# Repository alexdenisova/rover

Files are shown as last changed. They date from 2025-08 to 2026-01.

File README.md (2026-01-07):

# Rover

An STM32 + ESP32 remote controller for a Yandex Rover toy that executes voice commands: "Forward", "Backward", "Right", "Left", "Spin", "Open", "Close".

As OpenAI's Whisper is rather slow at transcribing the audio, it takes several seconds for the rover to react to the oral command. In the future, I plan to train my own speech-to-text model in the hopes of making it quicker.

## How it works

The user says one of the commands, which is recorded by the MAX9814 microphone either onto the SD card or to the ESP32. The ESP32 creates a WAV file from the audio and sends it to the "Speech-to-Text" server that uses OpenAI's Whisper to transcribe the audio. Then, based on the command received, the STM32 sends an IR signal to the rover, who then completes the command.

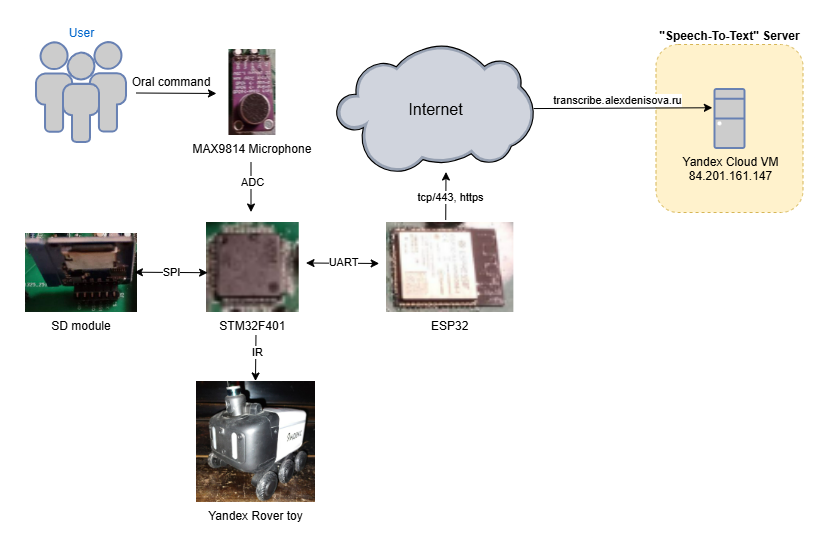
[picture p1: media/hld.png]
HLD

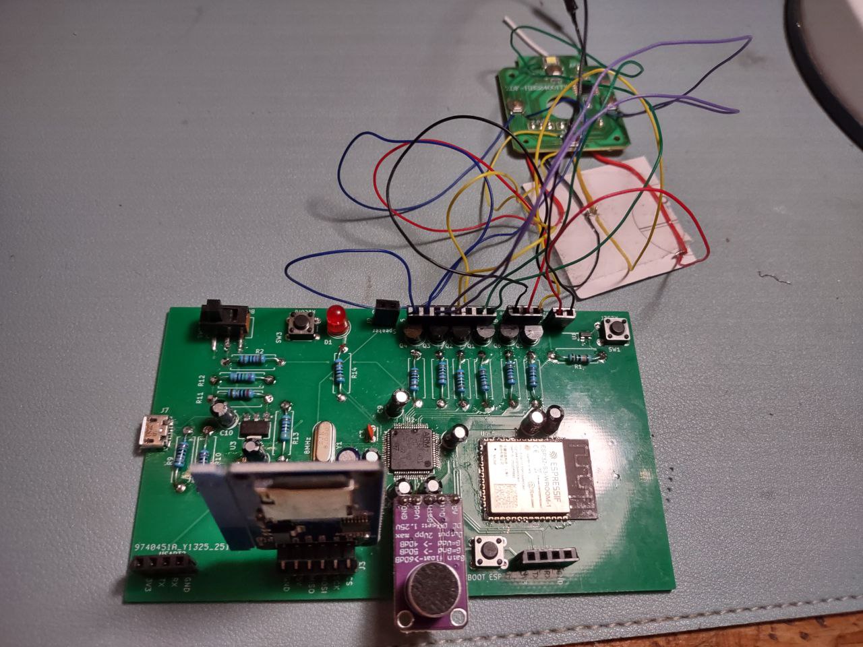
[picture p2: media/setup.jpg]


## Video

In the demonstration, I give the command "Forward". The rover takes several seconds to react, as the speech-to-text model is rather slow at transcribing.

https://github.com/user-attachments/assets/662a4837-75a4-4f81-b607-461e728f610d

## Photos

<p float="left">
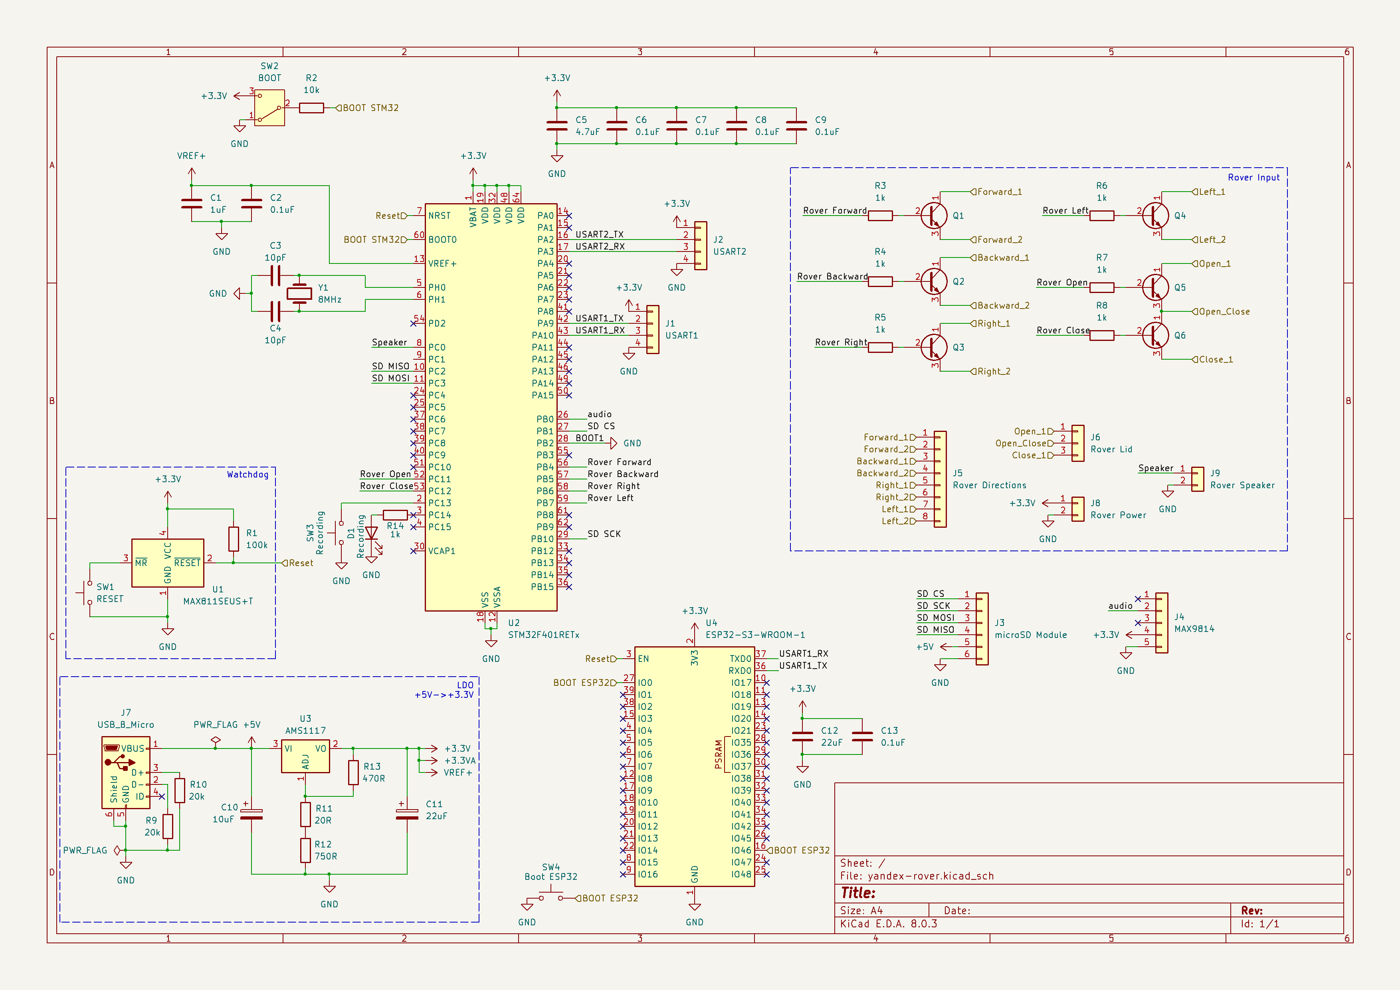
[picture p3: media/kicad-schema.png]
    
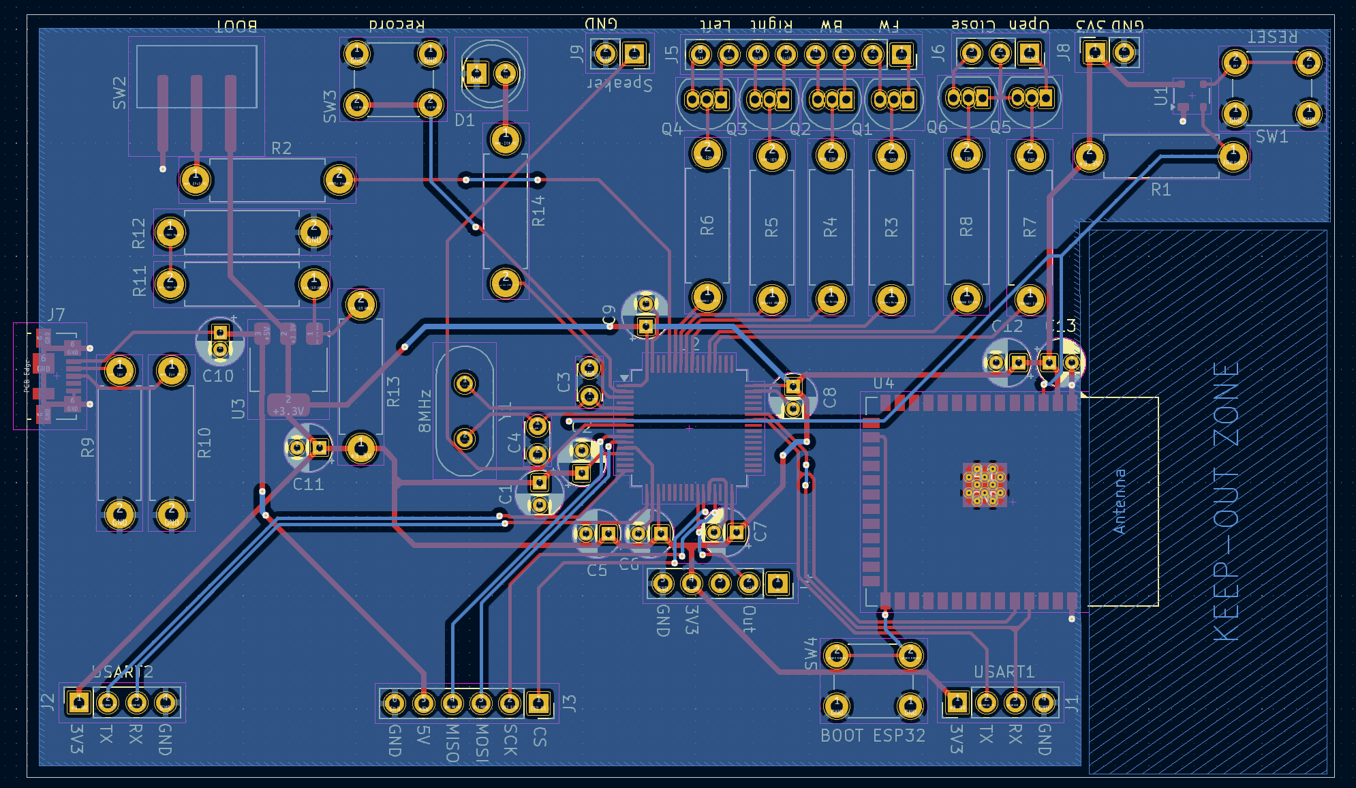
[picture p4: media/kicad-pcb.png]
    
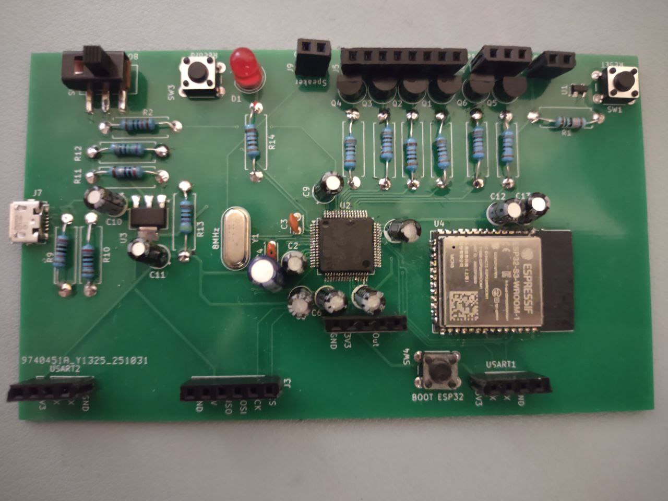
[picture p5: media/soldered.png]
    
</p>

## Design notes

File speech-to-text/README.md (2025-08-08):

# Speech-to-Text Server

A Speech-to-Text API based on OpenAI Whisper used to transcribe audio for Rover instructions. Currently, only one file at a time can be processed.

To transcribe audio use:
`curl -X POST -F "file=@/path/audio.wav" http://transcribe.alexdenisova.net/transcribe`

or with chunks:
`curl -X POST -H "Content-Range: bytes 0-1048999/2322510" -F "file=@/path/to/chunk" http://transcribe.alexdenisova.net/transcribe`

The server is deployed in a local cluster, which is located in the same network as the Rover.

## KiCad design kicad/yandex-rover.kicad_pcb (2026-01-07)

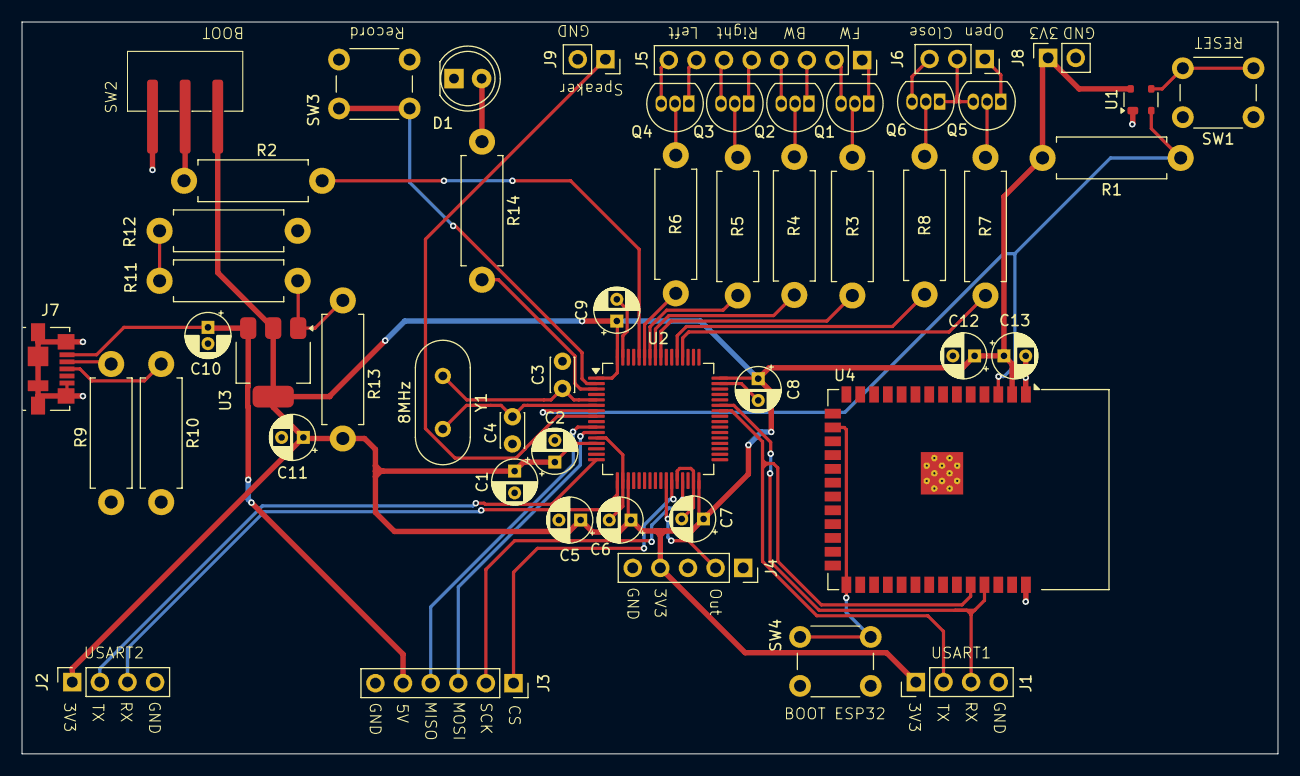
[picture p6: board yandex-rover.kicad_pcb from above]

Board: 2 copper layers, 115.5 x 67.3 mm, 52 parts (0 on the bottom side), 49 nets.

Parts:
C1: 1uF; CP_Radial_D4.0mm_P2.00mm
C2, C6, C7, C8, C9, C13: 0.1uF; CP_Radial_D4.0mm_P2.00mm
C3, C4: 10pF; C_Disc_D3.0mm_W2.0mm_P2.50mm
C5: 4.7uF; CP_Radial_D4.0mm_P2.00mm
C10: 10uF; CP_Radial_D4.0mm_P1.50mm
C11, C12: 22uF; CP_Radial_D4.0mm_P2.00mm
D1: Recording; LED_D5.0mm
J1: USART1; PinHeader_1x04_P2.54mm_Vertical
J2: USART2; PinSocket_1x04_P2.54mm_Vertical
J3: microSD Module; PinSocket_1x06_P2.54mm_Vertical
J4: MAX9814; PinSocket_1x05_P2.54mm_Vertical
J5: Rover Directions; PinSocket_1x08_P2.54mm_Vertical
J6: Rover Lid; PinSocket_1x03_P2.54mm_Vertical
J7: USB_B_Micro; USB_Micro-B_Molex_47346-0001
J8: Rover Power; PinSocket_1x02_P2.54mm_Vertical
J9: Rover Speaker; PinSocket_1x02_P2.54mm_Vertical
Q1, Q2, Q3, Q4, Q5, Q6: TO-92_Inline
R1: 100k; R_Axial_DIN0411_L9.9mm_D3.6mm_P12.70mm_Horizontal
R2: 10k; R_Axial_DIN0411_L9.9mm_D3.6mm_P12.70mm_Horizontal
R3, R4, R5, R6, R7, R8, R14: 1k; R_Axial_DIN0411_L9.9mm_D3.6mm_P12.70mm_Horizontal
R9, R10: 20k; R_Axial_DIN0411_L9.9mm_D3.6mm_P12.70mm_Horizontal
R11: 20R; R_Axial_DIN0411_L9.9mm_D3.6mm_P12.70mm_Horizontal
R12: 750R; R_Axial_DIN0411_L9.9mm_D3.6mm_P12.70mm_Horizontal
R13: 470R; R_Axial_DIN0411_L9.9mm_D3.6mm_P12.70mm_Horizontal
SW1: RESET; SW_PUSH_6mm_H4.3mm
SW2: BOOT; KLS7-SS-12F19-G5
SW3: Recording; SW_PUSH_6mm
SW4: Boot ESP32; SW_PUSH_6mm
U1: MAX811SEUS+T; SOT-143
U2: STM32F401RETx; LQFP-64_10x10mm_P0.5mm
U3: AMS1117; SOT-223-3_TabPin2
U4: ESP32-S3-WROOM-1
Y1: 8MHz; Crystal_HC49-4H_Vertical

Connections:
+3.3V: C1.1, C2.1, C5.1, C6.1, C7.1, C8.1, C9.1, C11.1, C12.1, C13.1, J1.1, J2.1, J4.4, J8.1, R1.2, R13.1, SW2.3 (C), U1.4 (VCC), U2.1 (VBAT), U2.13 (VREF+), U2.19 (VDD), U2.32 (VDD), U2.48 (VDD), U2.64 (VDD), U3.2 (VO), U4.2 (3V3)
+5V: C10.1, J3.5, J7.1 (VBUS), U3.3 (VI)
/BOOT ESP32: SW4.2, U4.16 (IO46), U4.27 (IO0)
/BOOT STM32: R2.2, U2.60 (BOOT0)
/Backward_1: J5.3, Q2.1 (C)
/Backward_2: J5.4, Q2.3 (E)
/Close_1: J6.3, Q6.3 (E)
/Forward_1: J5.1, Q1.1 (C)
/Forward_2: J5.2, Q1.3 (E)
/Left_1: J5.7, Q4.1 (C)
/Left_2: J5.8, Q4.3 (E)
/Open_1: J6.1, Q5.1 (C)
/Open_Close: J6.2, Q5.3 (E), Q6.1 (C)
/Reset: R1.1, U1.2 (~RESET), U2.7 (NRST), U4.3 (EN)
/Right_1: J5.5, Q3.1 (C)
/Right_2: J5.6, Q3.3 (E)
/Rover Backward: R4.1, U2.57 (PB5)
/Rover Close: R8.1, U2.53 (PC12)
/Rover Forward: R3.1, U2.56 (PB4)
/Rover Left: R6.1, U2.59 (PB7)
/Rover Open: R7.1, U2.52 (PC11)
/Rover Right: R5.1, U2.58 (PB6)
/SD CS: J3.1, U2.27 (PB1)
/SD MISO: J3.4, U2.10 (PC2)
/SD MOSI: J3.3, U2.11 (PC3)
/SD SCK: J3.2, U2.29 (PB10)
/Speaker: J9.1, U2.8 (PC0)
/USART1_RX: J1.3, U2.43 (PA10), U4.37 (TXD0)
/USART1_TX: J1.2, U2.42 (PA9), U4.36 (RXD0)
/USART2_RX: J2.3, U2.17 (PA3)
/USART2_TX: J2.2, U2.16 (PA2)
/audio: J4.2, U2.26 (PB0)
GND: C1.2, C2.2, C3.2, C4.2, C5.2, C6.2, C7.2, C8.2, C9.2, C10.2, C11.2, C12.2, C13.2, D1.1 (K), J1.4, J2.4, J3.6, J4.5, J7.5 (GND), J7.6 (Shield), J8.2, J9.2, R9.2, R10.2, R12.2, SW1.1, SW2.1 (A), SW3.1, SW4.1, U1.1 (GND), U2.12 (VSSA), U2.18 (VSS), U2.28 (PB2), U2.31 (VSS), U2.47 (VSS), U2.63 (VSS), U4.1 (GND), U4.40 (GND), U4.41 (GND)
unnamed: D1.2 (A), R14.1
unnamed: J7.3 (D+), R10.1
unnamed: J7.2 (D-), R9.1
unnamed: Q1.2 (B), R3.2
unnamed: Q2.2 (B), R4.2
unnamed: Q3.2 (B), R5.2
unnamed: Q4.2 (B), R6.2
unnamed: Q5.2 (B), R7.2
unnamed: Q6.2 (B), R8.2
unnamed: R11.2, R12.1
unnamed: R2.1, SW2.2 (B)
unnamed: SW1.2, U1.3 (~MR)
unnamed: SW3.2, U2.2 (PC13)
unnamed: C3.1, U2.5 (PH0), Y1.1
unnamed: C4.1, U2.6 (PH1), Y1.2
unnamed: R11.1, R13.2, U3.1 (ADJ)

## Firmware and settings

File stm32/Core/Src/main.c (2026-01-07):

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
/* Includes ------------------------------------------------------------------*/
#include "main.h"
#include "cmsis_os.h"
#include "fatfs.h"

/* USER CODE BEGIN Includes */
#include <string.h>
#include <stdio.h>
#include <stdbool.h>
#include <math.h>
#include <stdlib.h>
#include <ctype.h>
/* USER CODE END Includes */

/* USER CODE BEGIN PTD */

// WAV header structure
typedef struct {
  // RIFF Header
  char riff_header[4]; // Contains "RIFF". Marks the file as a riff file.
  uint32_t wav_size;   // Size of the overall file
  char wave_header[4]; // Contains "WAVE". File Type Header

  // Format Header
  char fmt_header[4]; // Contains "fmt ". Format chunk marker. Includes trailing null
  uint32_t fmt_chunk_size;  // Should be 16 for PCM
  uint16_t audio_format;    // Should be 1 for PCM
  uint16_t num_channels;
  uint32_t sample_rate;
  uint32_t byte_rate;       //  (Sample Rate * BitsPerSample * Channels) / 8
  uint16_t block_align;     // (BitsPerSample * Channels) / 8
  uint16_t bits_per_sample; // Bits per sample

  // Data Header
  char data_header[4]; // Contains "data". Data chunk marker
  uint32_t data_bytes; // Size of the data section
} WavHeader;

typedef enum {
  ROVER_DO_NOTHING,
  ROVER_FORWARD,
  ROVER_BACKWARD,
  ROVER_RIGHT,
  ROVER_LEFT,
  ROVER_SPIN,
  ROVER_OPEN,
  ROVER_CLOSE,
  ROVER_SPEAK
} RoverCommand;
/* USER CODE END PTD */

/* USER CODE BEGIN PD */
#define ADC_BUFFER_SIZE 4
#define UART_RX_BUFFER_SIZE 200
#define DATA_BUFFER_SIZE 200
#define BIT_0 ( 1 << 0 )
/* USER CODE END PD */

ADC_HandleTypeDef hadc1;
DMA_HandleTypeDef hdma_adc1;

SPI_HandleTypeDef hspi2;

TIM_HandleTypeDef htim3;

UART_HandleTypeDef huart1;
UART_HandleTypeDef huart2;

osThreadId audioTaskHandle;
osThreadId uartParseTaskHandle;
osThreadId roverTaskHandle;
osMessageQId audioQueueHandle;
osMutexId commandMutexHandle;
/* USER CODE BEGIN PV */
EventGroupHandle_t buttonEventHandle;

uint16_t audio_adc[ADC_BUFFER_SIZE];
uint32_t samples_taken = 0;

char uart_rx[UART_RX_BUFFER_SIZE];
bool received_uart_rx = false;

RoverCommand command = ROVER_DO_NOTHING;

const char *BARK_FILE_NAME = "bark.wav";

const uint32_t SAMPLE_RATE = 10000;
const uint16_t BITS_PER_SAMPLE = 16; // Half Word
const float DURATION = 1.0f;
const uint32_t NUMBER_OF_SAMPLES = SAMPLE_RATE * DURATION;
const uint16_t NUMBER_OF_CHANNELS = 1;
const uint32_t DATA_SIZE = NUMBER_OF_SAMPLES * NUMBER_OF_CHANNELS
    * BITS_PER_SAMPLE / 8;
const uint32_t FILE_SIZE = sizeof(WavHeader) + DATA_SIZE;
/* USER CODE END PV */

void SystemClock_Config(void);
static void MX_GPIO_Init(void);
static void MX_DMA_Init(void);
static void MX_USART2_UART_Init(void);
static void MX_SPI2_Init(void);
static void MX_USART1_UART_Init(void);
static void MX_TIM3_Init(void);
static void MX_ADC1_Init(void);
void vAudioTask(void const *argument);
void vUartParseTask(void const *argument);
void vRoverTask(void const *argument);

/* USER CODE BEGIN PFP */
void Set_GPIO_Tmp(GPIO_TypeDef *GPIOx, uint16_t GPIO_Pin, uint32_t time_ms);
/* USER CODE END PFP */

/* USER CODE BEGIN 0 */
static void UART_Log(char *str) {
  HAL_UART_Transmit(&huart2, (uint8_t*) str, strlen(str), HAL_MAX_DELAY);
}

#define UART_Transmit_ESP32(x) _Generic((x), \
    WavHeader*: HAL_UART_Transmit(&huart1, (uint8_t*) (x), sizeof(WavHeader), HAL_MAX_DELAY), \
    char*: HAL_UART_Transmit(&huart1, (uint8_t*) x, strlen((char*) x), HAL_MAX_DELAY))

static void UART_Transmit_Buffer_ESP32(int16_t *buffer, uint16_t buffer_idx) {
  HAL_UART_Transmit(&huart1, (uint8_t*) buffer, buffer_idx * sizeof(int16_t),
  HAL_MAX_DELAY);
}

static void UART_Receive_ESP32() {
  HAL_UARTEx_ReceiveToIdle_IT(&huart1, (uint8_t*) uart_rx, UART_RX_BUFFER_SIZE);
}

void Set_GPIO_T(GPIO_TypeDef *GPIOx, uint16_t GPIO_Pin, uint32_t time_ms) {
HAL_GPIO_WritePin(GPIOx, GPIO_Pin, GPIO_PIN_SET);
HAL_Delay(time_ms);
HAL_GPIO_WritePin(GPIOx, GPIO_Pin, GPIO_PIN_RESET);
}
/* USER CODE END 0 */

/**
 * @brief  The application entry point.
 * @retval int
 */
int main(void) {
  /* MCU Configuration--------------------------------------------------------*/

  /* Reset of all peripherals, Initializes the Flash interface and the Systick. */
  HAL_Init();

  /* Configure the system clock */
  SystemClock_Config();

  /* Initialize all configured peripherals */
  MX_GPIO_Init();
  MX_DMA_Init();
  MX_FATFS_Init();
  MX_USART2_UART_Init();
  MX_SPI2_Init();
  MX_USART1_UART_Init();
  MX_TIM3_Init();
  MX_ADC1_Init();
  /* USER CODE BEGIN 2 */
  HAL_TIM_Base_Start(&htim3);
  /* USER CODE END 2 */

  /* Create the mutex(es) */
  /* definition and creation of commandMutex */
  osMutexDef(commandMutex);
  commandMutexHandle = osMutexCreate(osMutex(commandMutex));

  /* USER CODE BEGIN RTOS_MUTEX */
  /* add mutexes, ... */
  /* USER CODE END RTOS_MUTEX */

  /* USER CODE BEGIN RTOS_SEMAPHORES */
  /* add semaphores, ... */
  /* USER CODE END RTOS_SEMAPHORES */

  /* USER CODE BEGIN RTOS_TIMERS */
  /* start timers, add new ones, ... */
  /* USER CODE END RTOS_TIMERS */

  /* Create the queue(s) */
  /* definition and creation of audioQueue */
  osMessageQDef(audioQueue, 30000, int16_t);
  audioQueueHandle = osMessageCreate(osMessageQ(audioQueue), NULL);

  /* USER CODE BEGIN RTOS_QUEUES */
  buttonEventHandle = xEventGroupCreate();
  /* add queues, ... */
  /* USER CODE END RTOS_QUEUES */

  /* Create the thread(s) */
  /* definition and creation of audioTask */
  osThreadDef(audioTask, vAudioTask, osPriorityNormal, 0, 2200);
  audioTaskHandle = osThreadCreate(osThread(audioTask), NULL);

  /* definition and creation of uartParseTask */
  osThreadDef(uartParseTask, vUartParseTask, osPriorityNormal, 0, 128);
  uartParseTaskHandle = osThreadCreate(osThread(uartParseTask), NULL);

  /* definition and creation of roverTask */
  osThreadDef(roverTask, vRoverTask, osPriorityNormal, 0, 128);
  roverTaskHandle = osThreadCreate(osThread(roverTask), NULL);

  /* USER CODE BEGIN RTOS_THREADS */
  /* add threads, ... */
  /* USER CODE END RTOS_THREADS */

  /* Start scheduler */
  osKernelStart();
  /* We should never get here as control is now taken by the scheduler */
  /* Infinite loop */
  /* USER CODE BEGIN WHILE */
  while (1) {
    /* USER CODE END WHILE */

    /* USER CODE BEGIN 3 */
  }
  /* USER CODE END 3 */
}

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
/* USER CODE BEGIN 4 */
void HAL_GPIO_EXTI_Callback(uint16_t GPIO_Pin) {
  // If button pressed, set Event flag and start ADC
  if (GPIO_Pin == GPIO_PIN_13) {
    EventBits_t uxBits = xEventGroupGetBitsFromISR(buttonEventHandle);
    if ((uxBits & BIT_0) == 0) { // If Event flag not set
      UART_Log("Recording\n");
      HAL_GPIO_WritePin(Recording_LED_GPIO_Port, Recording_LED_Pin,
          GPIO_PIN_SET); // Turn on recording LED

      HAL_ADC_Start_DMA(&hadc1, (uint32_t*) audio_adc, ADC_BUFFER_SIZE);

      BaseType_t xHigherPriorityTaskWoken = pdFALSE; // TODO: awaken audiotask
      xEventGroupSetBitsFromISR(buttonEventHandle, BIT_0,
          &xHigherPriorityTaskWoken);
    }
  }
}

void HAL_ADC_ConvCpltCallback(ADC_HandleTypeDef *hadc) {
  int16_t adc;
  for (int i = 0; i < ADC_BUFFER_SIZE; i++) {
    // Map ADC data to int16_t
    adc = (int16_t) (((uint64_t) audio_adc[i]) * INT16_MAX * 2 / 4095
        + INT16_MIN);

    // Add data to queue
    xQueueSendFromISR(audioQueueHandle, &adc, portMAX_DELAY);

    samples_taken++;
    if (samples_taken == NUMBER_OF_SAMPLES) {
      HAL_ADC_Stop_DMA(hadc);
      UART_Log("Finished recording\n");
      HAL_GPIO_WritePin(Recording_LED_GPIO_Port, Recording_LED_Pin,
          GPIO_PIN_RESET); // Turn off recording LED
      samples_taken = 0;
    }
  }
}

void HAL_UARTEx_RxEventCallback(UART_HandleTypeDef *huart, uint16_t Size) {
  received_uart_rx = true;
}

// Creates the WAV header and sends it via UART to ESP32
void Write_WAV_Header() {
  // Fill in WAV header struct
  WavHeader header;
  memcpy(header.riff_header, "RIFF", 4);
  header.wav_size = DATA_SIZE + sizeof(WavHeader) - 8;
  memcpy(header.wave_header, "WAVE", 4);
  memcpy(header.fmt_header, "fmt ", 4);
  header.fmt_chunk_size = 16;
  header.audio_format = 1; // PCM
  header.num_channels = NUMBER_OF_CHANNELS;
  header.sample_rate = SAMPLE_RATE;
  header.bits_per_sample = BITS_PER_SAMPLE;
  header.byte_rate = DATA_SIZE;
  header.block_align = NUMBER_OF_CHANNELS * BITS_PER_SAMPLE / 8;
  memcpy(header.data_header, "data", 4);
  header.data_bytes = DATA_SIZE;

  // Send header to ESP32
UART_Transmit_ESP32(&header);
}

/**
 * @brief  Sets GPIO output temporarily for time_ms milliseconds.
 * @retval None
 */
void Set_GPIO_Tmp(GPIO_TypeDef *GPIOx, uint16_t GPIO_Pin, uint32_t time_ms) {
HAL_GPIO_WritePin(GPIOx, GPIO_Pin, GPIO_PIN_SET);
osDelay(time_ms);
HAL_GPIO_WritePin(GPIOx, GPIO_Pin, GPIO_PIN_RESET);
}
/* USER CODE END 4 */

/* USER CODE BEGIN Header_vAudioTask */
/**
 * @brief  Function implementing the audioTask thread.
 * @param  argument: Not used
 * @retval None
 */
/* USER CODE END Header_vAudioTask */
void vAudioTask(void const *argument) {
/* USER CODE BEGIN 5 */
const TickType_t xDelay = 1 / portTICK_PERIOD_MS;

int16_t data_buffer[DATA_BUFFER_SIZE];
uint16_t buffer_idx = 0;
bool sending_file = false; // Resets after the file has been sent
uint32_t data_sent = 0; // Number of bytes from data batch sent to ESP32

/* Infinite loop */
for (;;) {
  EventBits_t uxBits = xEventGroupGetBits(buttonEventHandle);
  if ((uxBits & BIT_0) != 0) {
    if (!sending_file) {
      // Transmit file size
      char uart_buffer[20];
      sprintf(uart_buffer, "%lu\n", FILE_SIZE);
      UART_Transmit_ESP32(uart_buffer);
      // Transmit header of WAV file
      Write_WAV_Header();
      sending_file = true;
    }
    int16_t data;
    while (xQueueReceive(audioQueueHandle, &data, 0)) {
      data_buffer[buffer_idx++] = data;
      UBaseType_t data_left = uxQueueMessagesWaitingFromISR(audioQueueHandle);

      if ((buffer_idx == DATA_BUFFER_SIZE) || (data_left == 0)) {
        // If buffer is full or there is no more data left in queue, then send buffer contents to ESP32
        UART_Transmit_Buffer_ESP32(data_buffer, buffer_idx);
        data_sent += buffer_idx;
        // Empty buffer
        memset(data_buffer, '\0', sizeof(data_buffer));
        buffer_idx = 0;
      }
    }
    if (data_sent == NUMBER_OF_SAMPLES) {
      UART_Log("WAV file sent successfully\n");
      UART_Receive_ESP32();
      // Return to initial state
      xEventGroupClearBits(buttonEventHandle, BIT_0);
      data_sent = 0;
      sending_file = false;
    }
  }
  osDelay(xDelay * 1000);
}
/* USER CODE END 5 */
}

/* USER CODE BEGIN Header_vUartParseTask */
/**
 * @brief Function implementing the uartParseTask thread.
 * @param argument: Not used
 * @retval None
 */
/* USER CODE END Header_vUartParseTask */
void vUartParseTask(void const *argument) {
/* USER CODE BEGIN vUartParseTask */
/* Infinite loop */
for (;;) {
  if (received_uart_rx) {
    // If received error message
    if (strncmp(uart_rx, "Error:", strlen("Error:")) == 0) {
      UART_Log(uart_rx);
    } else {
      // Trim "Success: " from message
      size_t l = strlen("Success: ");
      char *transcription =
          strncmp(uart_rx, "Success: ", l) ? uart_rx : uart_rx + l;
      // Make message lowercase
      for (int i = 0; transcription[i]; i++) {
        transcription[i] = tolower(transcription[i]);
      }

      xSemaphoreTake(commandMutexHandle, portMAX_DELAY);
      if (strstr(transcription, "forward") != NULL) {
        command = ROVER_FORWARD;
      } else if (strstr(transcription, "backward") != NULL) {
        command = ROVER_BACKWARD;
      } else if (strstr(transcription, "right") != NULL) {
        command = ROVER_RIGHT;
      } else if (strstr(transcription, "left") != NULL) {
        command = ROVER_LEFT;
      } else if (strstr(transcription, "spin") != NULL) {
        command = ROVER_SPIN;
      } else if (strstr(transcription, "open") != NULL) {
        command = ROVER_OPEN;
      } else if (strstr(transcription, "close") != NULL) {
        command = ROVER_CLOSE;
      } else {
        UART_Log("No instructions detected. Transcription: ");
        UART_Log(transcription);
      }
      xSemaphoreGive(commandMutexHandle);
    }
    received_uart_rx = false;
  }
  osDelay(1);
}
/* USER CODE END vUartParseTask */
}

/* USER CODE BEGIN Header_vRoverTask */
/**
 * @brief Function implementing the roverTask thread.
 * @param argument: Not used
 * @retval None
 */
/* USER CODE END Header_vRoverTask */
void vRoverTask(void const *argument) {
/* USER CODE BEGIN vRoverTask */
RoverCommand cmd;
/* Infinite loop */
for (;;) {
  xSemaphoreTake(commandMutexHandle, portMAX_DELAY);
  cmd = command;
  command = ROVER_DO_NOTHING;
  xSemaphoreGive(commandMutexHandle);
  if (cmd != ROVER_DO_NOTHING) {
    switch (cmd) {
    case ROVER_FORWARD:
      UART_Log("Forward!\n");
      Set_GPIO_Tmp(Rover_Forward_GPIO_Port, Rover_Forward_Pin, 500); // Go forward for 500ms
      break;
    case ROVER_BACKWARD:
      UART_Log("Backward!\n");
      Set_GPIO_Tmp(Rover_Backward_GPIO_Port, Rover_Backward_Pin, 500); // Go backward for 500ms
      break;
    case ROVER_RIGHT:
      UART_Log("Right!\n");
      Set_GPIO_Tmp(Rover_Right_GPIO_Port, Rover_Right_Pin, 200); // Turn right 90deg
      break;
    case ROVER_LEFT:
      UART_Log("Left!\n");
      Set_GPIO_Tmp(Rover_Left_GPIO_Port, Rover_Left_Pin, 200); // Turn left 90deg
      break;
    case ROVER_SPIN:
      UART_Log("Spin!\n");
      Set_GPIO_Tmp(Rover_Right_GPIO_Port, Rover_Right_Pin, 850); // Do a 360deg spin
      break;
    case ROVER_OPEN:
      UART_Log("Open lid!\n");
      Set_GPIO_Tmp(Rover_Open_GPIO_Port, Rover_Open_Pin, 1500); // Open lid
      break;
    case ROVER_CLOSE:
      UART_Log("Close lid!\n");
      Set_GPIO_Tmp(Rover_Close_GPIO_Port, Rover_Close_Pin, 1500); // Close lid
      break;
    case ROVER_SPEAK:
      // TODO
      break;
    }
  }
  osDelay(1);
}
/* USER CODE END vRoverTask */
}

/**
 * @brief  Period elapsed callback in non blocking mode
 * @note   This function is called  when TIM1 interrupt took place, inside
 * HAL_TIM_IRQHandler(). It makes a direct call to HAL_IncTick() to increment
 * a global variable "uwTick" used as application time base.
 * @param  htim : TIM handle
 * @retval None
 */
void HAL_TIM_PeriodElapsedCallback(TIM_HandleTypeDef *htim) {
if (htim->Instance == TIM1) {
  HAL_IncTick();
}
}

/**
 * @brief  This function is executed in case of error occurrence.
 * @retval None
 */
void Error_Handler(void) {
/* USER CODE BEGIN Error_Handler_Debug */
/* User can add his own implementation to report the HAL error return state */
__disable_irq();
while (1) {
}
/* USER CODE END Error_Handler_Debug */
}

#ifdef  USE_FULL_ASSERT
/**
  * @brief  Reports the name of the source file and the source line number
  *         where the assert_param error has occurred.
  * @param  file: pointer to the source file name
  * @param  line: assert_param error line source number
  * @retval None
  */
void assert_failed(uint8_t *file, uint32_t line)
{
  /* USER CODE BEGIN 6 */
  /* User can add his own implementation to report the file name and line number,
     ex: printf("Wrong parameters value: file %s on line %d\r\n", file, line) */
  /* USER CODE END 6 */
}
#endif /* USE_FULL_ASSERT */

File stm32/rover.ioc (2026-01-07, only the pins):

Mcu.UserName=STM32F401RETx
PA10.Signal=USART1_RX
PA13.GPIO_Label=TMS
PA13.Signal=SYS_JTMS-SWDIO
PA14.GPIO_Label=TCK
PA14.Signal=SYS_JTCK-SWCLK
PA2.GPIO_Label=USART_TX
PA2.Signal=USART2_TX
PA3.GPIO_Label=USART_RX
PA3.Signal=USART2_RX
PA9.Signal=USART1_TX
PB0.GPIO_Label=Recording_Output
PB0.Signal=ADCx_IN8
PB1.GPIO_Label=SD_CS
PB1.Signal=GPIO_Output
PB10.GPIO_Label=SD_SCK
PB10.Signal=SPI2_SCK
PB4.GPIO_Label=Rover_Forward
PB4.Signal=GPIO_Output
PB5.GPIO_Label=Rover_Backward
PB5.Signal=GPIO_Output
PB6.GPIO_Label=Rover_Right
PB6.Signal=GPIO_Output
PB7.GPIO_Label=Rover_Left
PB7.Signal=GPIO_Output
PC0.GPIO_Label=Recording_LED
PC0.Signal=GPIO_Output
PC11.GPIO_Label=Rover_Open
PC11.Signal=GPIO_Output
PC12.GPIO_Label=Rover_Close
PC12.Signal=GPIO_Output
PC13-ANTI_TAMP.GPIO_Label=Recording_Button
PC13-ANTI_TAMP.Signal=GPXTI13
PC2.GPIO_Label=SD_MISO
PC2.Signal=SPI2_MISO
PC3.GPIO_Label=SD_MOSI
PC3.Signal=SPI2_MOSI

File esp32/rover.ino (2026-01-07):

#include <WiFi.h>
#include <my_secrets.h>

const char* SSID = SECRET_SSID;
const char* WIFI_PASSWORD = SECRET_WIFI_PASSWORD;
const char* serverURL = "http://transcribe.alexdenisova.ru/transcribe";

// HTTP server config:
const String SERVER_NAME = "transcribe.alexdenisova.ru";
const uint16_t SERVER_PORT = 80;
const String HTTP_PATH = "/transcribe";

// Buffer for file data
const size_t BUFFER_SIZE = 8192;  // 8KB chunks
uint8_t fileBuffer[BUFFER_SIZE];

#define HTTP_TIMEOUT 10000                // 10 second timeout for HTTP request/response
const String FORM_BOUNDARY = "boundary";  // the multipart/form-data boundary

WiFiClient client;

void setup() {
  Serial.setRxBufferSize(20000);
  Serial.begin(250000);

  WiFi.mode(WIFI_STA);
  WiFi.begin(SSID, WIFI_PASSWORD);

  Serial.println("Connecting to WiFi...");
  while (WiFi.status() != WL_CONNECTED) {
    delay(500);
    Serial.print(".");
  }
  Serial.println("\nConnected to WiFi!");
}

void loop() {
  // Expecting data stream with format "<file size>\n<file bytes>"
  if (Serial.available() > 0) {
    uint32_t file_size = readFileSize();
    if ((file_size != 0) && readAndSendFile(file_size)) {
      awaitResponse();
    }

    // Clear RX buffer to wait for new file
    while (Serial.available()) {
      Serial.read();
    }
  }

  delay(1);
}

// Get file size from RX
uint32_t readFileSize() {
  uint32_t file_size = 0;
  while (Serial.available() > 0) {
    char data = Serial.read();
    if (data != '\n') {
      if (data < '0' || '9' < data) {
        Serial.println("Error: Expected format '<file size>\n<file bytes>'");
        return 0;
      }
      file_size = file_size * 10 + data - '0';
    } else {
      // Finished receiving file size
      return file_size;
    }
  }
  return 0;
}


// Reads file from RX and sends it to server
// Returns 'true' if successfully sent HTTP request
bool readAndSendFile(uint32_t file_size) {
  // Connect to server
  client.connect(SERVER_NAME.c_str(), SERVER_PORT);
  if (!client.connected()) {
    // Send connection error to STM32
    Serial.println("Error: Could not connect to server");
    return false;
  }

  // Send HTTP request with headers
  client.println("POST " + HTTP_PATH + " HTTP/1.1");
  client.println("Host: " + SERVER_NAME);
  client.println("Content-Type: multipart/form-data; boundary=" + FORM_BOUNDARY);

  String header = "--" + FORM_BOUNDARY + "\r\nContent-Disposition: form-data; name=\"file\"; filename=\"audio.WAV\"\r\nContent-Type: application/octet-stream\r\n\r\n";
  String footer = "\r\n--" + FORM_BOUNDARY + "--\r\n";
  uint32_t contentLength = header.length() + footer.length() + file_size;
  client.println("Content-Length: " + String(contentLength));
  client.println();
  client.print(header);

  // Read file bytes from RX and send it to server in chunks
  unsigned long uploadStart = millis();
  size_t totalSent = 0;
  while (totalSent < file_size) {
    if (Serial.available() > 0) {
      size_t toRead = min(int(BUFFER_SIZE), int(file_size - totalSent));
      size_t bytesRead = Serial.readBytes(fileBuffer, toRead);

      if (bytesRead > 0) {
        client.write(fileBuffer, bytesRead);
        totalSent += bytesRead;

        if (totalSent == file_size) {
          break;
        }
      }
    }

    // Check for timeout
    if (millis() - uploadStart > HTTP_TIMEOUT) {
      // Send upload error to STM32
      Serial.println("Error: Upload timeout");
      return false;
    }
    delay(1);
  }

  // Send multipart body footer
  client.print(footer);
  return true;
}

// Waits for response from server
void awaitResponse() {
  int statusCode;
  String responseBody;
  unsigned long responseStart = millis();
  while (millis() - responseStart < HTTP_TIMEOUT) {
    if (parseHttpResponse(client, statusCode, responseBody)) {
      responseBody.trim();
      responseBody.toLowerCase();
      if (statusCode >= 200 && statusCode < 300) {
        // Send response body to STM32
        Serial.println("Success: " + responseBody);
      } else {
        // Send HTTP error to STM32
        Serial.printf("Error: Status: %d, Body: %s\n", statusCode, responseBody.c_str());
      }
      client.stop();
      return;
    }
    delay(10);
  }

  // Send timeout error to STM32
  Serial.println("Error: Timed out waiting for response");
  client.stop();
  return;
}

// Parses the HTTP status code and response body
// Returns 'true' if successfully parsed response
bool parseHttpResponse(WiFiClient& client, int& statusCode, String& responseBody) {
  statusCode = 0;
  responseBody = "";

  if (!client.connected() || !client.available()) {
    return false;
  }

  // Read status line
  String statusLine = client.readStringUntil('\n');
  if (statusLine.length() == 0) {
    return false;
  }

  // Parse status code
  int firstSpace = statusLine.indexOf(' ');
  int secondSpace = statusLine.indexOf(' ', firstSpace + 1);
  if (firstSpace == -1 || secondSpace == -1) {
    return false;
  }

  statusCode = statusLine.substring(firstSpace + 1, secondSpace).toInt();

  // Read headers
  int contentLength = -1;
  while (client.available()) {
    String line = client.readStringUntil('\n');
    line.trim();

    if (line.length() == 0) {
      break;  // End of headers
    }

    if (line.startsWith("Content-Length:")) {
      int colonPos = line.indexOf(':');
      contentLength = line.substring(colonPos + 1).toInt();
    }
  }

  // Read body
  if (contentLength == 0) {
    return true;
  } else if (contentLength > 0) {
    // Read exact number of bytes
    char buffer[contentLength + 1];
    int bytesRead = client.readBytes(buffer, contentLength);
    buffer[bytesRead] = '\0';
    responseBody = String(buffer);
  } else {
    // Read until connection closes
    while (client.available()) {
      responseBody += (char)client.read();
    }
  }
  return true;
}

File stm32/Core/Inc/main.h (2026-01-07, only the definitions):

#define Recording_Button_Pin GPIO_PIN_13
#define Recording_Button_GPIO_Port GPIOC
#define Recording_Button_EXTI_IRQn EXTI15_10_IRQn
#define Recording_LED_Pin GPIO_PIN_0
#define Recording_LED_GPIO_Port GPIOC
#define SD_MISO_Pin GPIO_PIN_2
#define SD_MISO_GPIO_Port GPIOC
#define SD_MOSI_Pin GPIO_PIN_3
#define SD_MOSI_GPIO_Port GPIOC
#define USART_TX_Pin GPIO_PIN_2
#define USART_TX_GPIO_Port GPIOA
#define USART_RX_Pin GPIO_PIN_3
#define USART_RX_GPIO_Port GPIOA
#define Recording_Output_Pin GPIO_PIN_0
#define Recording_Output_GPIO_Port GPIOB
#define SD_CS_Pin GPIO_PIN_1
#define SD_CS_GPIO_Port GPIOB
#define SD_SCK_Pin GPIO_PIN_10
#define SD_SCK_GPIO_Port GPIOB
#define TMS_Pin GPIO_PIN_13
#define TMS_GPIO_Port GPIOA
#define TCK_Pin GPIO_PIN_14
#define TCK_GPIO_Port GPIOA
#define Rover_Open_Pin GPIO_PIN_11
#define Rover_Open_GPIO_Port GPIOC
#define Rover_Close_Pin GPIO_PIN_12
#define Rover_Close_GPIO_Port GPIOC
#define Rover_Forward_Pin GPIO_PIN_4
#define Rover_Forward_GPIO_Port GPIOB
#define Rover_Backward_Pin GPIO_PIN_5
#define Rover_Backward_GPIO_Port GPIOB
#define Rover_Right_Pin GPIO_PIN_6
#define Rover_Right_GPIO_Port GPIOB
#define Rover_Left_Pin GPIO_PIN_7
#define Rover_Left_GPIO_Port GPIOB

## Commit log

2026-01-07 added stm32, esp32, kicad
    [yandex-rover-B_Cu.gbr, yandex-rover-B_Mask.gbr, yandex-rover-B_Paste.gbr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]
2026-01-07 changed stm32 pins

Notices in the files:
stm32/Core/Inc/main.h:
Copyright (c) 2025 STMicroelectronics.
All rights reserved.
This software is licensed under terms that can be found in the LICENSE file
